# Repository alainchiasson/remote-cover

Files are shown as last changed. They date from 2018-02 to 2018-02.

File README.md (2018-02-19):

# Remote control cover

One day I found a weird plastic piece and I threw it out. I had been using a
programable multi remote for a while so I never noticed it came from my tv
remote!! Now that I have a 3D printer, and my multi-remote is starting to show
its age, I figured I would print out a new cover.

# Verions

| Version | Changes | Results |
|---|---|---|
| 0.1 | Initial | some measurements were off, eg: cover was 24mm wide, but the interior should have been 24mm |
| 0.2 | Widened body to 24mm interior, modified release clip. |  Body not deep enough, missing a little on the width (.5mm), release clip too thick. Holding clips too thick. Not long enough |
| 0.3 | Reduced the of the thickness of the clips and the release, made clips shorter, increased the with a little. increased length 2mm |  Forgot to widen the body! Also 6mm is too high. Clips are great. There is also a slight curve between the body and the case on the release clip end |
| 0.4 |  Widened body by 1mm -> 25mm. Shortened from 6mm back to 5mm. Added a curve on the sides on the end of the retainer.|  Release clip pushes down too much. Corner curve is not big enough. |
| 0.5 | Increase radius to 0.75mm. thicken release clip by 1mm and move the rest inwards so clip is bellow cover line. |  "Perfect !!" |

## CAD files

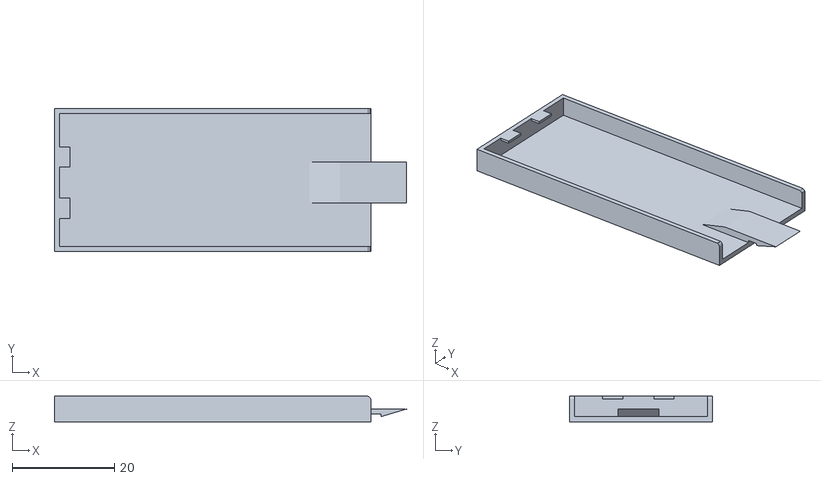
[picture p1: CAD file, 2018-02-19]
stl_history/remote_cover_1_0.stl
69.0 x 28.0 x 5.00

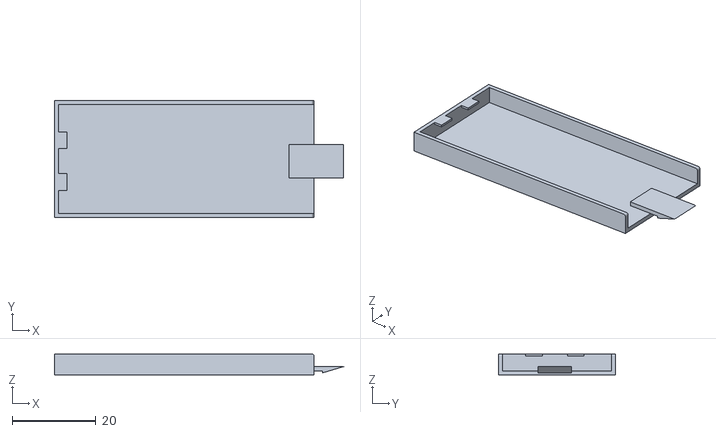
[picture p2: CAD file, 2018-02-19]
stl_history/remote_cover_0_4.stl
69.0 x 28.0 x 5.00

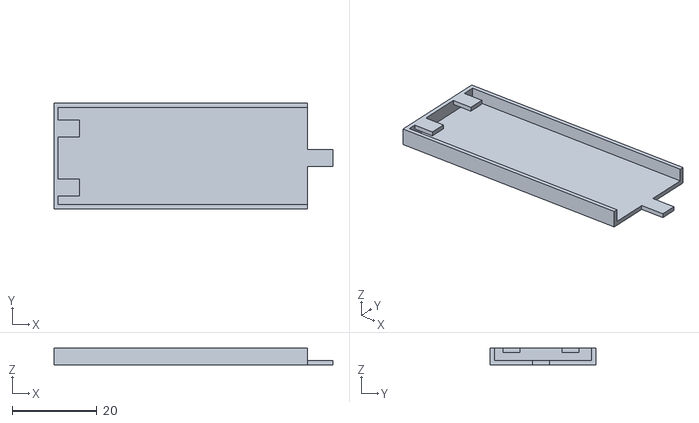
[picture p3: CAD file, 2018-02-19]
stl_history/remote_cover_0_1.stl
66.0 x 25.0 x 4.00

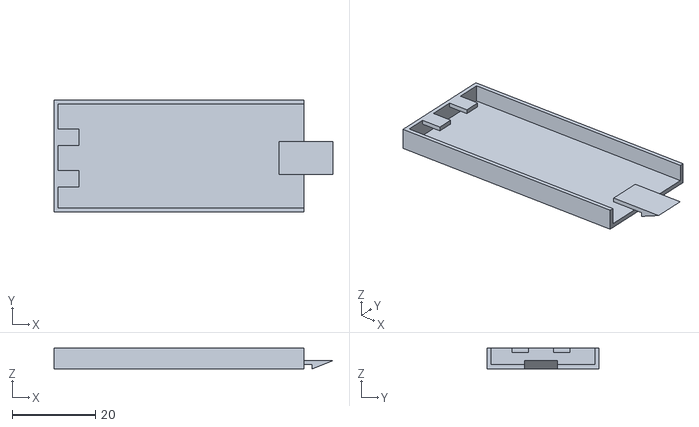
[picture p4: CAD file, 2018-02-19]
stl_history/remote_cover_0_2.stl
67.0 x 27.0 x 5.00

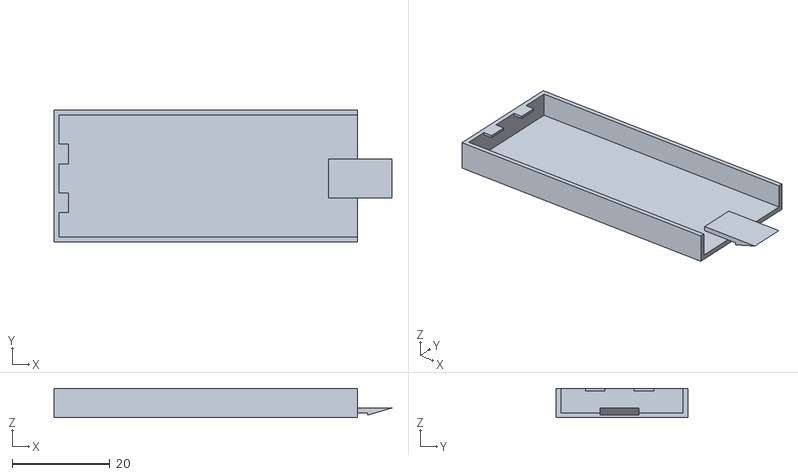
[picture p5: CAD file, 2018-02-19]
stl_history/remote_cover_0_3.stl
69.0 x 27.0 x 6.00

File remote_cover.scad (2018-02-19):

// Build the bottom of the box

// Sizes
height = 5;
thickness = 1;
clip_thickness = 0.5;
clip_width = 4;
clip_depth = 3;
span = 62;
inside_width = 25;
outside_width = inside_width + 2* thickness;
total_height = height + thickness;

release_width = 8;
release_thickness = 1.5;

module release() {
  rotate([90,180,0]) {
    translate([0,0,-release_width])
    linear_extrude(release_width) polygon(points=[[0,-2.5], [0,0], [10,0] ]);
  }
  cube([6, release_width, 2.5 * thickness]);
  translate([6, 0, 1.5 * thickness]) cube([2, release_width, thickness ]);
  rotate([90,0,0]) {
    translate([8,2.5,-release_width])
    linear_extrude(release_width) polygon(points=[[0,-release_thickness], [0,0], [5,0] ]);
  }
}

module clip() {
  cube([clip_depth, clip_width ,clip_thickness]);
}

module bottom() {
  cube([span,outside_width,thickness]);
  translate([span-6,(outside_width-release_width)/2,0]) release();
}

module side() {
  union (){
    cube([span-0.5,thickness,height]);
    translate([span-0.5,0,0]) cube([0.5, thickness, height-0.5]);
    rotate([90,0,0]) translate([span-0.75,height-0.75,-thickness/2]) cylinder($fn=30, r=0.75, h=1, center=true);
  }
}

module end() {
  cube([1,outside_width,height]);
  a = clip_width*2 + 6;
  b = (outside_width - a)/2;
  c = b + clip_width + 6;
  translate([0, b ,height -clip_thickness]) clip();
  translate([0, c ,height -clip_thickness]) clip();
  /* translate([0, (outside_width-clip_width)/2 ,height -1]) color("red") clip(); */
}

/* release(); */
/* bottom (); */
/* end(); */
union() {
  translate([-span/2,-outside_width/2,0]) bottom();
  translate([-span/2,-outside_width/2,0]) side();
  translate([-span/2,+outside_width/2,0]) side();
  translate([-span/2,-outside_width/2,0]) end();
}

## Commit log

2018-02-18 First print
    [remote_cover.scad]
2018-02-18 Fixed first pass issues and added clip.
    [remote_cover.scad]
2018-02-18 Fixed dimmenesions after 2nd print.
    [remote_cover.scad]
2018-02-18 Added curverd corners, fixed width issue.
    [remote_cover.scad]
2018-02-19 Modified curve and thickness of release clip
    [remote_cover.scad]
2018-02-19 Added historical STLs - for my own pleasure :-)
    [remote_cover_0_1.stl, remote_cover_0_2.stl, remote_cover_0_3.stl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]
